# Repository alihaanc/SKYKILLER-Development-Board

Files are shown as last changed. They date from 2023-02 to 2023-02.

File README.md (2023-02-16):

# SKYKILLER-Development-Board
Drone and Rocket Development PCB board





## Different Color
sdsd







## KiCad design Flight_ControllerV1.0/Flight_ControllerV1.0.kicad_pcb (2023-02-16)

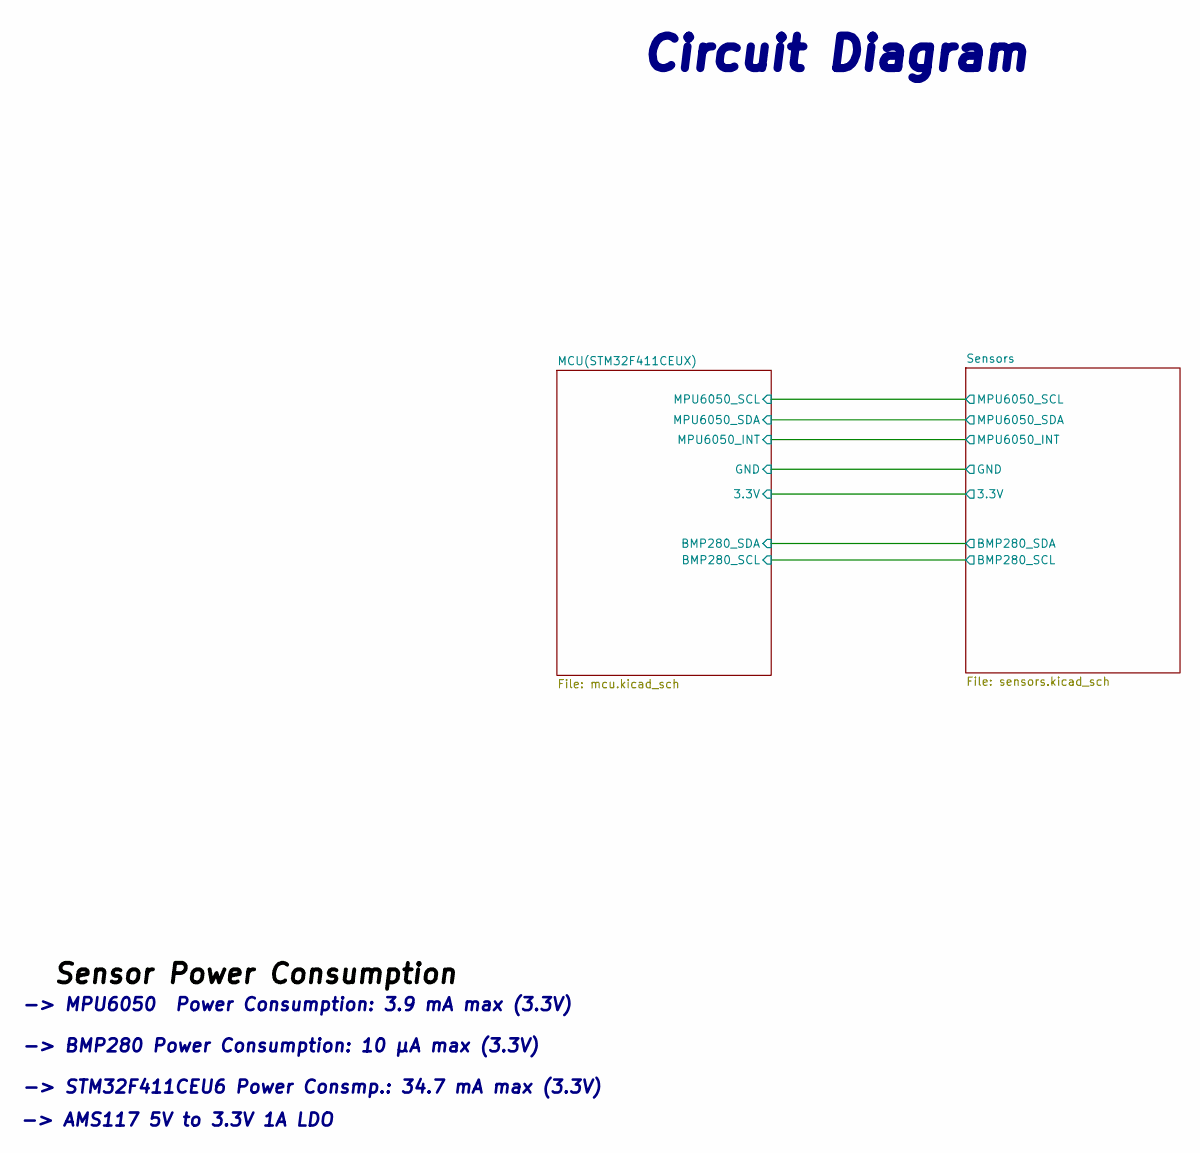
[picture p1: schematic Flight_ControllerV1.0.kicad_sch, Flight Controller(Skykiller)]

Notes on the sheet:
-> AMS117 5V to 3.3V 1A LDO
Circuit Diagram
-> MPU6050 Power Consumption: 3.9 mA max (3.3V)
-> BMP280 Power Consumption: 10 μA max (3.3V)
-> STM32F411CEU6 Power Consmp.: 34.7 mA max (3.3V)

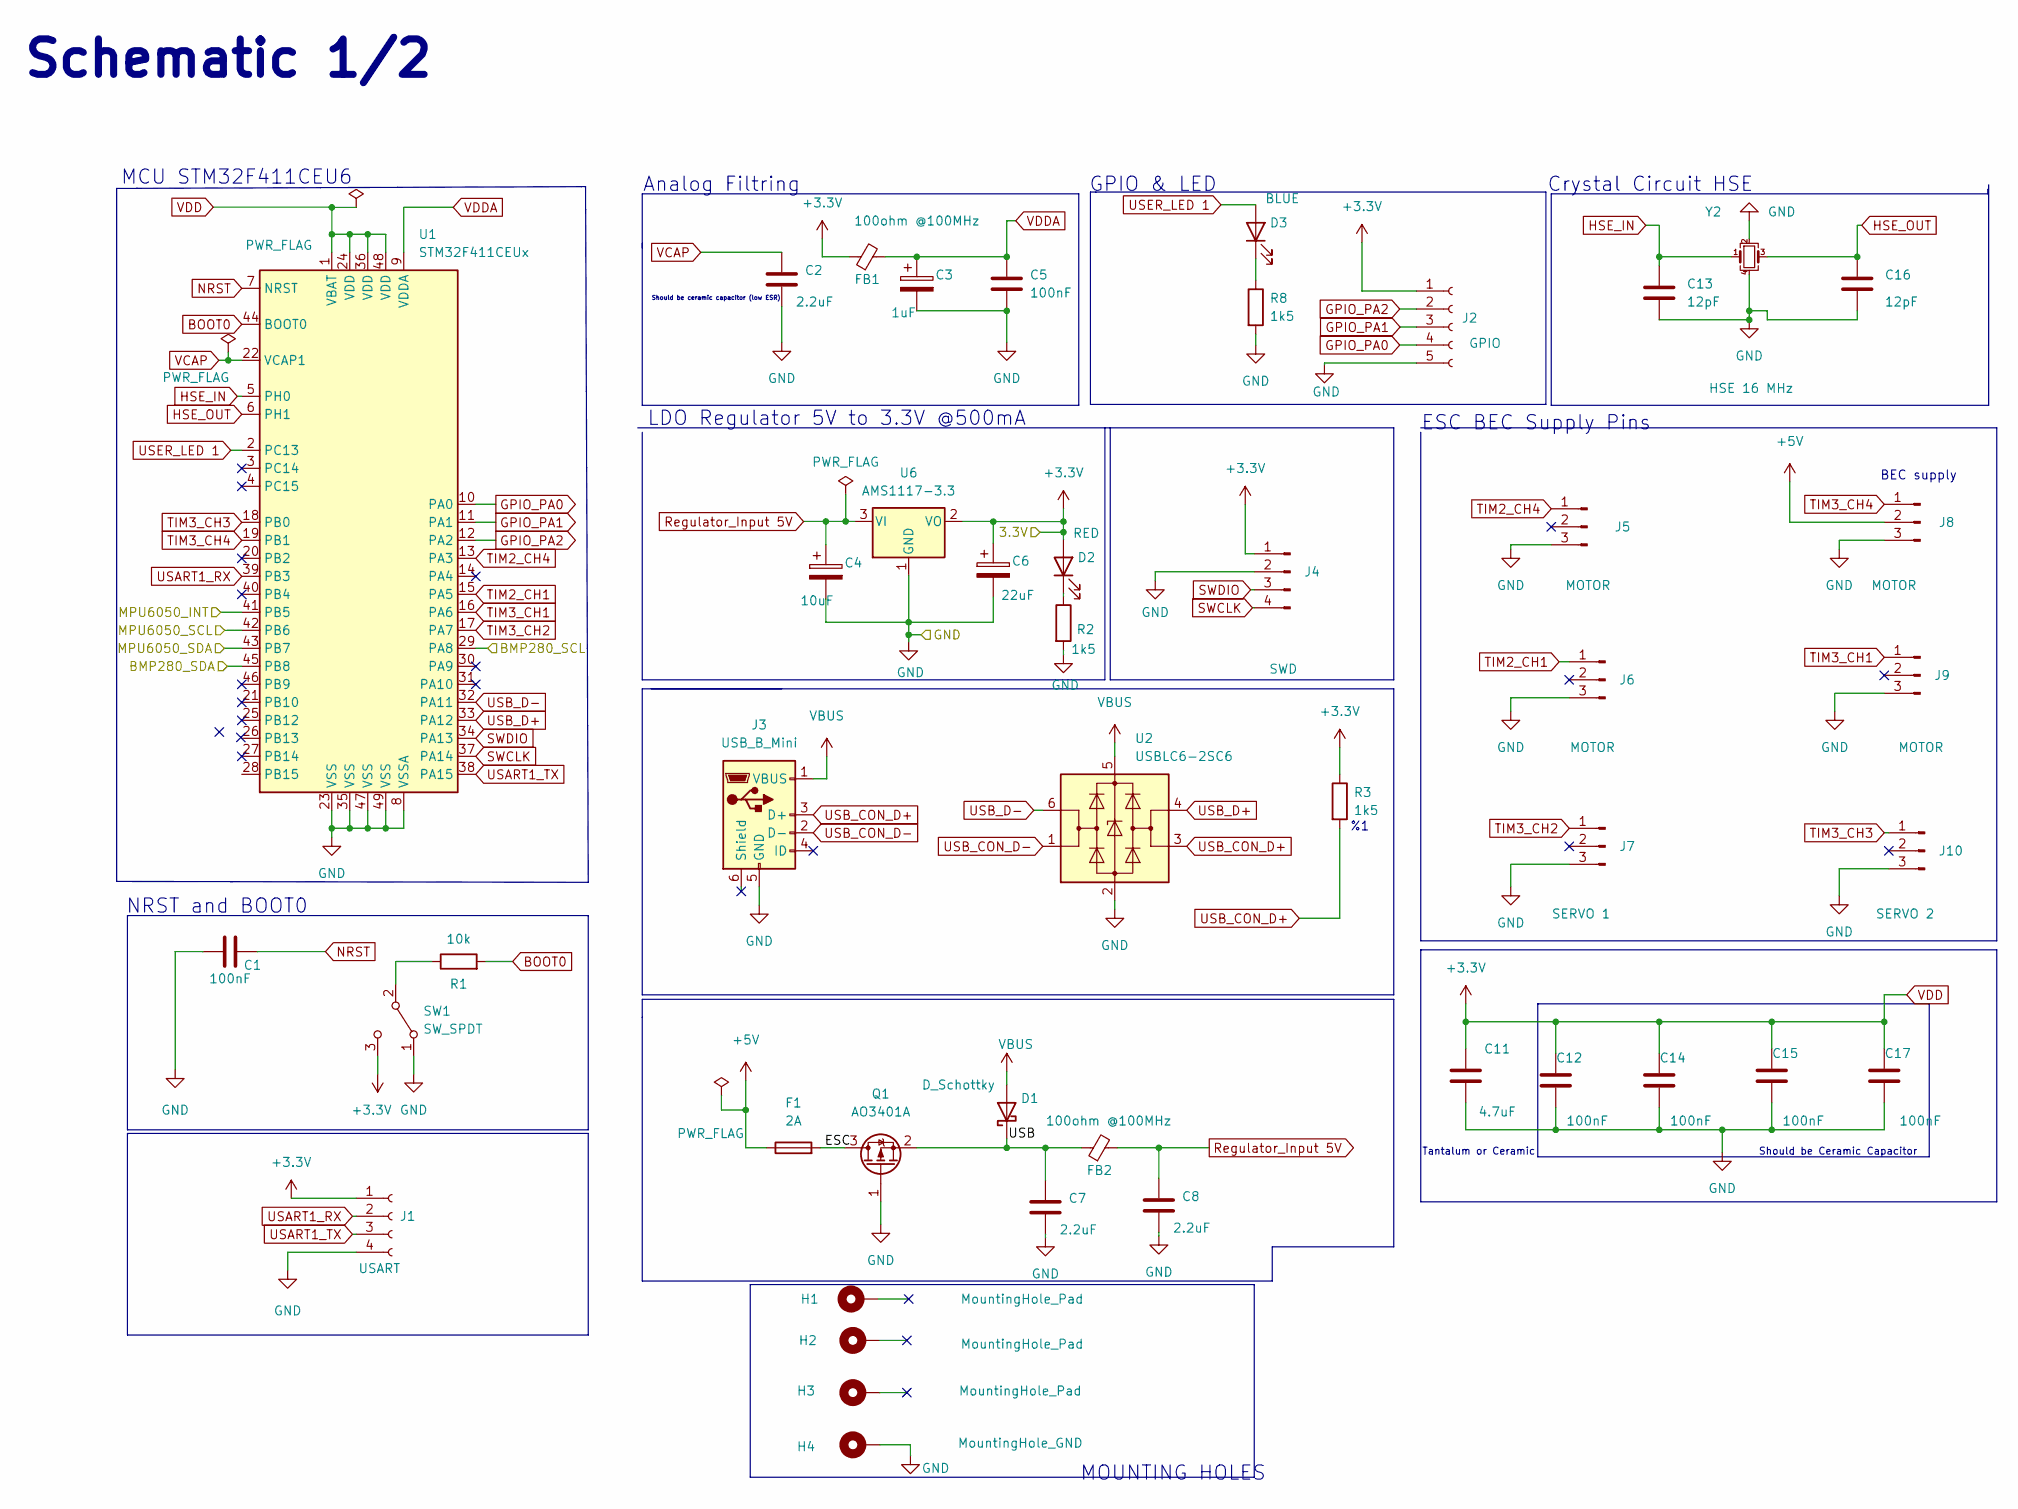
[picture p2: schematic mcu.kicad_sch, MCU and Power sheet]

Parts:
C1, C5, C12, C14, C15, C17: 100nF; C_0603_1608Metric
C2, C7, C8: 2.2uF; C_0603_1608Metric
C3: 1uF; CP_Elec_4x5.4
C4: 10uF; CP_Elec_4x5.4
C6: 22uF; CP_Elec_4x5.4
C11: 4.7uF; C_0603_1608Metric
C13, C16: 12pF; C_0402_1005Metric
D1: D_Schottky; D_SOD-123F
D2: RED; LED_0805_2012Metric
D3: BLUE; LED_0805_2012Metric
F1: 2A; Fuse_0603_1608Metric
FB1, FB2: 100ohm @100MHz; L_0805_2012Metric
H1, H2, H3: MountingHole_Pad; MountingHole_4.3mm_M4_Pad_Via
H4: MountingHole_GND; MountingHole_4.3mm_M4_Pad_Via
J1: USART; PinHeader_1x04_P2.54mm_Horizontal
J2: GPIO; PinHeader_1x05_P2.54mm_Horizontal
J3: USB_B_Mini; USB_Mini-B_Wuerth_65100516121_Horizontal
J4: SWD; PinHeader_1x04_P2.54mm_Vertical
J5, J6, J8, J9: MOTOR; PinHeader_1x03_P2.54mm_Vertical
J7: SERVO 1; PinHeader_1x03_P2.54mm_Vertical
J10: SERVO 2; PinHeader_1x03_P2.54mm_Vertical
Q1: AO3401A; SOT-23
R1: 10k; R_0603_1608Metric
R2, R3: 1k5; R_0201_0603Metric
R8: 1k5; R_0603_1608Metric
SW1: SW_SPDT; SW_SPDT_PCM12
U1: STM32F411CEUx; QFN-48-1EP_7x7mm_P0.5mm_EP5.6x5.6mm
U2: USBLC6-2SC6; SOT-23-6
U6: AMS1117-3.3; SOT-223-3_TabPin2
Y2: HSE 16 MHz; Crystal_SMD_3225-4Pin_3.2x2.5mm

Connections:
+3.3V: C6.1, C11.1, C12.2, C14.2, C15.2, C17.2, D2.2 (A), FB1.1, J1.1, J2.1, J4.1, R3.1, SW1.3 (C), U1.1 (VBAT), U1.24 (VDD), U1.36 (VDD), U1.48 (VDD), U6.2 (VO); also elsewhere on the board
+5V: F1.1, J8.2
/MCU(STM32F411CEUX)/BMP280_SCL: U1.29 (PA8); also elsewhere on the board
/MCU(STM32F411CEUX)/BMP280_SDA: U1.45 (PB8); also elsewhere on the board
/MCU(STM32F411CEUX)/ESC: F1.2, Q1.3 (D)
/MCU(STM32F411CEUX)/MPU6050_INT: U1.41 (PB5); also elsewhere on the board
/MCU(STM32F411CEUX)/MPU6050_SCL: U1.42 (PB6); also elsewhere on the board
/MCU(STM32F411CEUX)/MPU6050_SDA: U1.43 (PB7); also elsewhere on the board
BOOT0: R1.2, U1.44 (BOOT0)
GND: C1.1, C2.2, C3.2, C4.2, C5.2, C6.2, C7.2, C8.2, C11.2, C12.1, C13.2, C14.1, C15.1, C16.2, C17.1, H4.1, J1.4, J2.5, J3.5 (GND), J4.2, J5.3, J6.3, J7.3, J8.3, J9.3, J10.3, Q1.1 (G), R2.2, R8.2, SW1.1 (A), U1.8 (VSSA), U1.23 (VSS), U1.35 (VSS), U1.47 (VSS), U1.49 (VSS), U2.2 (GND), U6.1 (GND), Y2.2, Y2.4; also elsewhere on the board
GPIO_PA0: J2.4, U1.10 (PA0)
GPIO_PA1: J2.3, U1.11 (PA1)
GPIO_PA2: J2.2, U1.12 (PA2)
HSE_IN: C13.1, U1.5 (PH0), Y2.1
HSE_OUT: C16.1, U1.6 (PH1), Y2.3
NRST: C1.2, U1.7 (NRST)
unnamed: C7.1, D1.1 (K), FB2.1, Q1.2 (S)
unnamed: D2.1 (K), R2.1
unnamed: D3.1 (K), R8.1
unnamed: R1.1, SW1.2 (B)
Regulator_Input 5V: C4.1, C8.1, FB2.2, U6.3 (VI)
SWCLK: J4.4, U1.37 (PA14)
SWDIO: J4.3, U1.34 (PA13)
TIM2_CH1: J6.1, U1.15 (PA5)
TIM2_CH4: J5.1, U1.13 (PA3)
TIM3_CH1: J9.1, U1.16 (PA6)
TIM3_CH2: J7.1, U1.17 (PA7)
TIM3_CH3: J10.1, U1.18 (PB0)
TIM3_CH4: J8.1, U1.19 (PB1)
USART1_RX: J1.2, U1.39 (PB3)
USART1_TX: J1.3, U1.38 (PA15)
USB_CON_D+: J3.3 (D+), R3.2, U2.3 (I/O2)
USB_CON_D-: J3.2 (D-), U2.1 (I/O1)
USB_D+: U1.33 (PA12), U2.4 (I/O2)
USB_D-: U1.32 (PA11), U2.6 (I/O1)
USER_LED 1: D3.2 (A), U1.2 (PC13)
VBUS: D1.2 (A), J3.1 (VBUS), U2.5 (VBUS)
VCAP: C2.1, U1.22 (VCAP1)
VDDA: C3.1, C5.1, FB1.2, U1.9 (VDDA)

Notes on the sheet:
ESC BEC Supply Pins
BEC supply
Should be Ceramic Capacitor
Tantalum or Ceramic
GPIO & LED
Should be ceramic capacitor (low ESR)
MCU STM32F411CEU6
MOUNTING HOLES
Crystal Circuit HSE
LDO Regulator 5V to 3.3V @500mA
Analog Filtring
Schematic 1/2
NRST and BOOT0

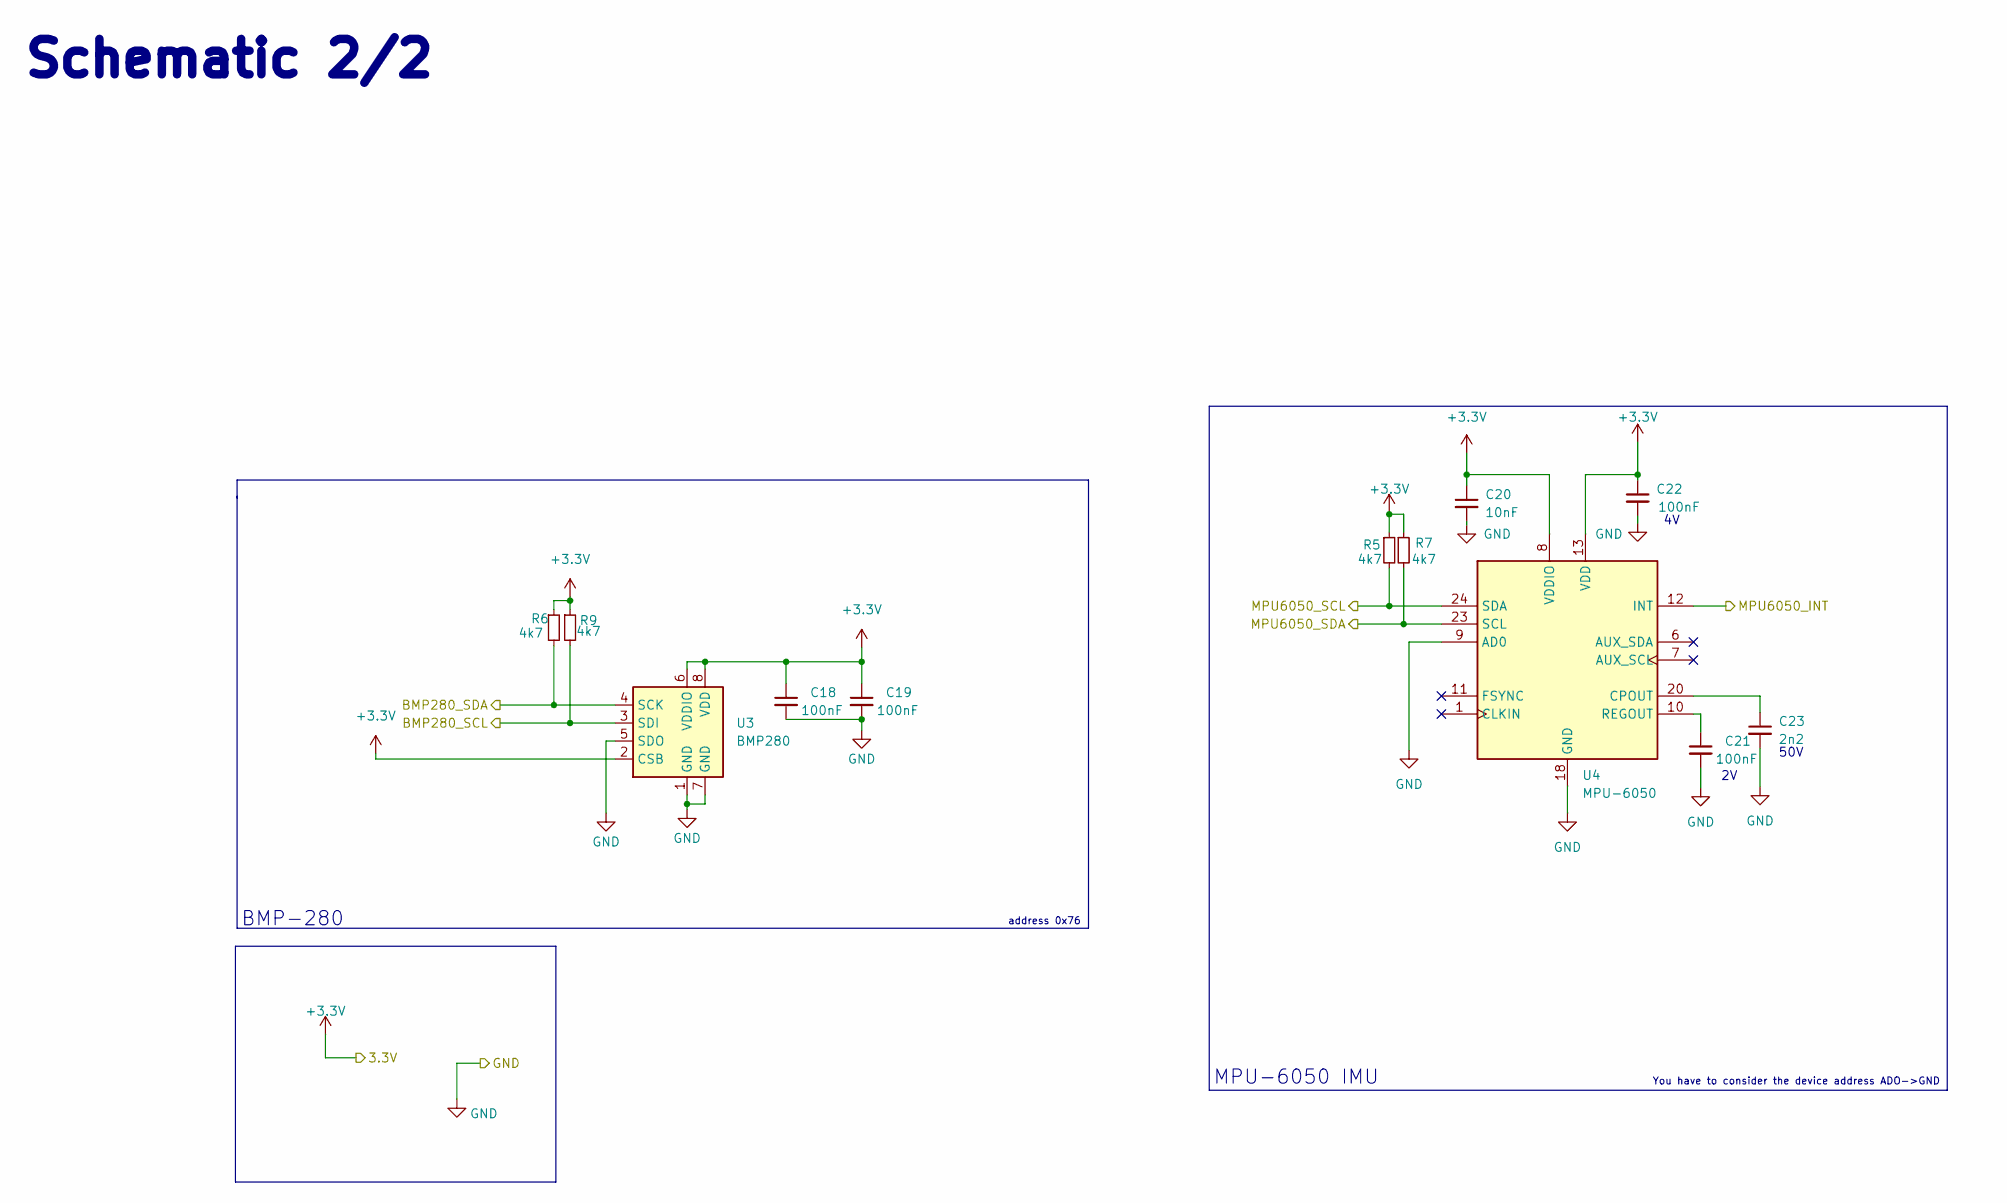
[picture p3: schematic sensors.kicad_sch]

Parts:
C18, C19, C21, C22: 100nF; C_0603_1608Metric
C20: 10nF; C_0402_1005Metric
C23: 2n2; C_0603_1608Metric
R5, R6, R7, R9: 4k7; R_0603_1608Metric
U3: BMP280; Bosch_LGA-8_2x2.5mm_P0.65mm_ClockwisePinNumbering
U4: MPU-6050; InvenSense_QFN-24_4x4mm_P0.5mm

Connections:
+3.3V: C18.1, C19.1, C20.1, C22.1, R5.1, R6.1, R7.1, R9.1, U3.2 (CSB), U3.6 (VDDIO), U3.8 (VDD), U4.8 (VDDIO), U4.13 (VDD); also elsewhere on the board
/MCU(STM32F411CEUX)/BMP280_SCL: R9.2, U3.3 (SDI); also elsewhere on the board
/MCU(STM32F411CEUX)/BMP280_SDA: R6.2, U3.4 (SCK); also elsewhere on the board
/MCU(STM32F411CEUX)/MPU6050_INT: U4.12 (INT); also elsewhere on the board
/MCU(STM32F411CEUX)/MPU6050_SCL: R5.2, U4.24 (SDA); also elsewhere on the board
/MCU(STM32F411CEUX)/MPU6050_SDA: R7.2, U4.23 (SCL); also elsewhere on the board
GND: C18.2, C19.2, C20.2, C21.2, C22.2, C23.2, U3.1 (GND), U3.5 (SDO), U3.7 (GND), U4.9 (AD0), U4.18 (GND); also elsewhere on the board
unnamed: C21.1, U4.10 (REGOUT)
unnamed: C23.1, U4.20 (CPOUT)

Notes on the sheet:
Schematic 2/2
address 0x76
BMP-280
50V
You have to consider the device address ADO->GND
MPU-6050 IMU

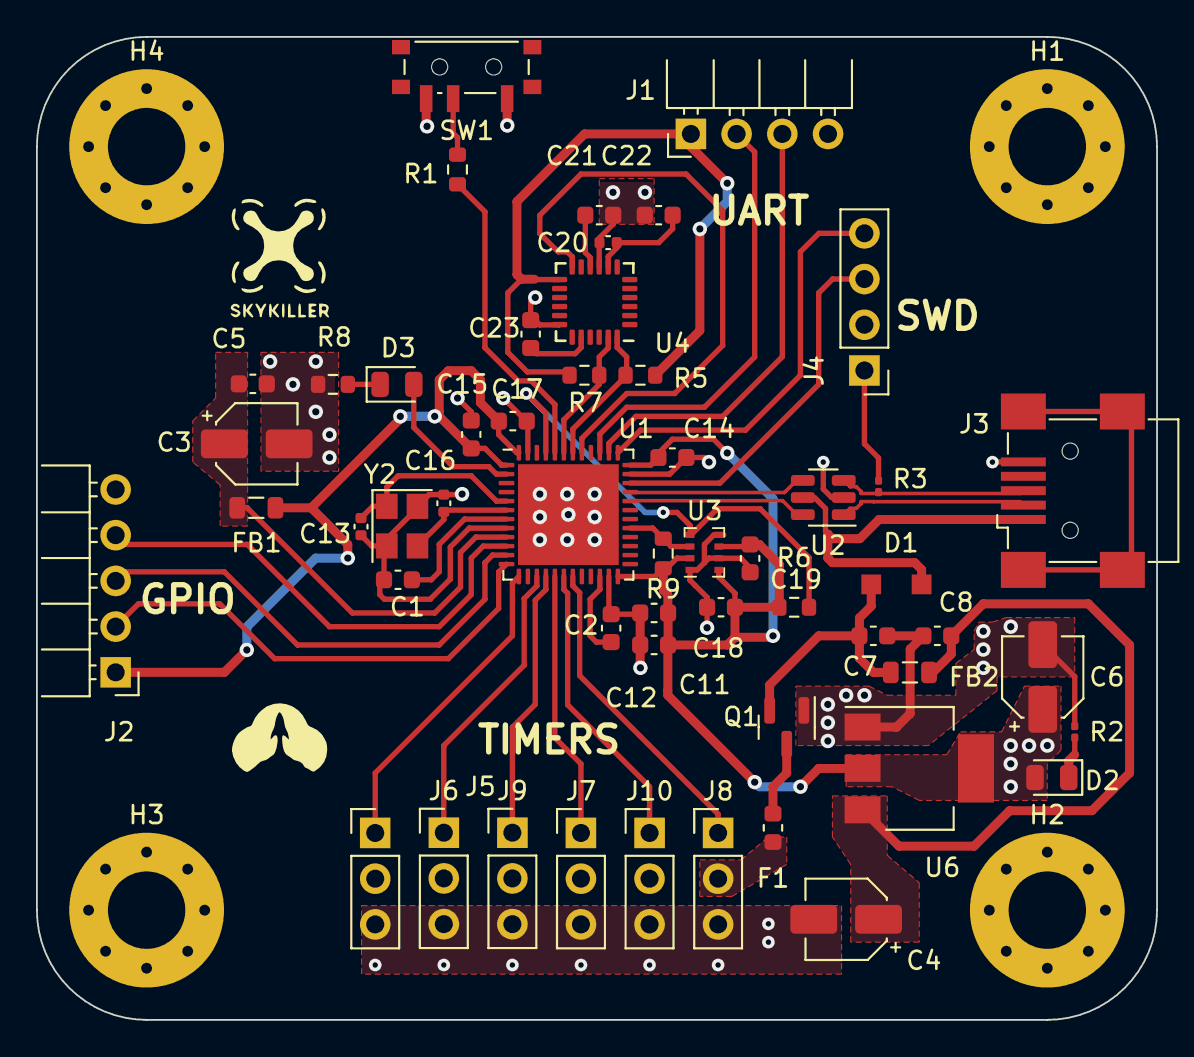
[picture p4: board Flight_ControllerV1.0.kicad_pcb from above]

Board: 4 copper layers, 62.2 x 54.6 mm, 57 parts (0 on the bottom side), 41 nets.
